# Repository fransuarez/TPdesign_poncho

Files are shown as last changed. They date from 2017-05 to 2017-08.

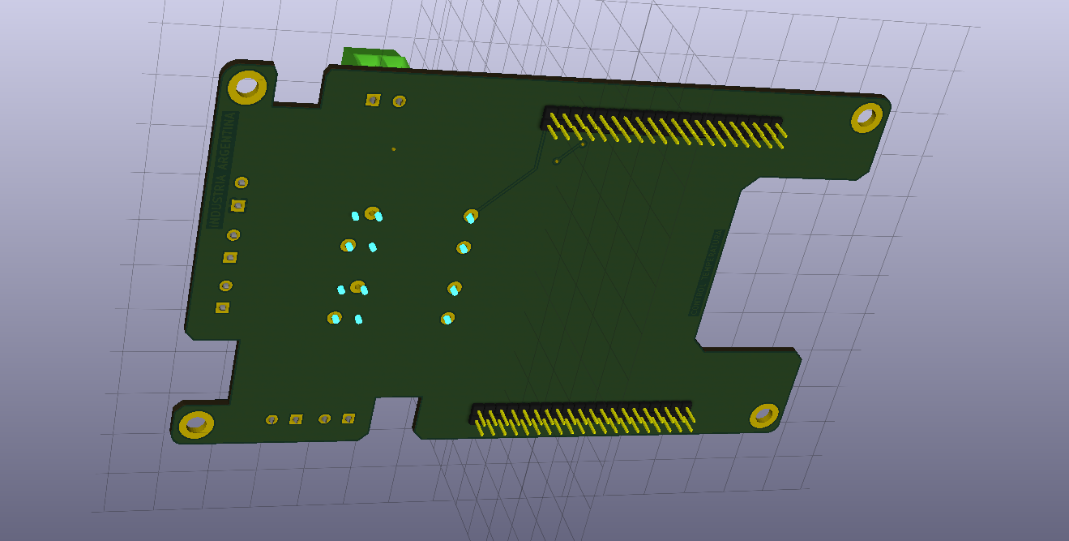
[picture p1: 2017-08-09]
Docs/tempRelayPoncho_BOTTOM.png

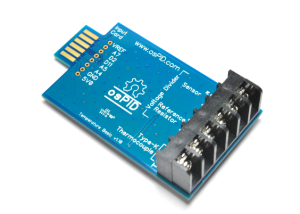
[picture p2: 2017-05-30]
Docs/osPID/osPIDInputTemperatureBasicBoard-300x214.png

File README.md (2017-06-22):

# TPdesign_poncho
Nombre corto del proyecto: 
Interfaz de termocupla K mas salidas a Relay

Autor:
Francisco Suárez

Fecha de este documento::

28 Mayo de 2017

Licencia:
BSD
GPL V3, Open Hardware

Descripción:
Es una poncho destinado a intermediar con termocuplas mas el control de dos interruptores a traves de relays, pensado para hacer control de temperatura en un tanque de agua a travez de resistencias.

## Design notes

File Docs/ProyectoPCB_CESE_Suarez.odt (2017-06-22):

Curso de Diseño de PCBs - CESE

Hoja de presentación de proyecto

Nombre corto del proyecto:

Interfaz de termocupla K mas salidas a Relay

Autor:

Francisco Suárez

Fecha de este documento::

28 Mayo de 2017

Licencia:

BSD

GPL V3, Open Hardware

Repositorio de trabajo:

https://github.com/fransuarez/TPdesign_poncho.git

Descripción:

Es una poncho destinado a intermediar con termocuplas mas el control de dos interruptores a traves de relays, pensado para hacer control de temperatura en un tanque de agua a travez de resistencias.

Requisitos del profesor:

Requisitos comunes:

1. Licencia abierta (se tiene que poder publicar los archivos KiCad y la funcionalidad del circuito).
2. Utilizar Kicad 4.0.x.
3. Consolidar toda la documentación en forma organizada dentro del directorio de proyecto de KiCad.
4. Aplicar una licencia o aclarar el Copyright.
5. Considerar en cada caso, los aspectos vistos referente a documentación.
6. Realizar diseño jerárquico salvo en circuitos muy pequeños.
7. Siempre que sea posible, considerar para los diseños componentes que se consigan en el mercado local.
8. Se utilizará como proveedor de referencia a Mayer (para las reglas de diseño).
9. Indicar que tipo/calidad de placa se considera para el diseño, intentando siempre que sea posible, seleccionar la de menor costo.

10. Pcb de dos capas.

Tareas y Alcance:

Indicar hasta donde se pretende llegar con el diseño y que tareas involucra. Por ejemplo:

1. Búsqueda de esquemáticos de referencia. (Obligatorio)
2. Adaptaciones de esquemático.
3. Ingreso de esquemático a Kicad. (Obligatorio)
4. Revisión del esquemático por un tercero. (Obligatorio)
5. Cálculo de presupuesto y proveedores de componentes. (Obligatorio)
6. Selección de footprints. (Obligatorio)
7. Ubicación de componentes. (Necesario para una buena calificación)
8. Ruteo. (Depende lo acordado)
9. Generación de Gerbers. (Depende lo acordado)

Enlaces:

http://ospid.com/blog/download/

https://github.com/osPID

Imágenes:

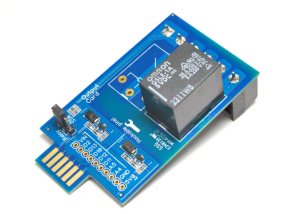
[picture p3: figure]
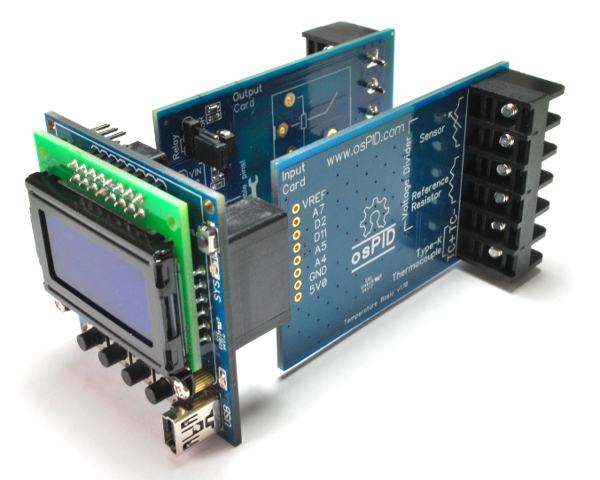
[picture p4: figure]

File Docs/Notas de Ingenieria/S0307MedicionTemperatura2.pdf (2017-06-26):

## TERMORRESISTENCIAS (RTD)

- La termorresistencia trabaja según el principio de que en la medida que varía la temperatura, su resistencia se modifica, y la magnitud de esta modificación puede relacionarse con la variación de temperatura.
- Las termorresistencias de uso más común se fabrican de alambres finos soportados por un material aislante y luego encapsulados.
- El elemento encapsulado se inserta luego dentro de una vaina o tubo metálico cerrado en un extremo que se llena con un polvo aislante y se sella con cemento para impedir que absorba humedad.

## TERMORRESISTENCIAS (RTD)

- La relación fundamental para el funcionamiento es:
- Rt = Ro * (1 + α * t)
- Ro: resistencia en ohmios a 0 grados Celsius
- Rt: resistencia en ohmios a t grados Celsius
- Alpha: coeficiente de temperatura de la resistencia. Los materiales utilizados para los arrollamientos de termorresistencias son fundamentalmente platino, níquel, níquel-hierro, cobre y tungsteno.

## TERMORRESISTENCIAS (RTD)

- El platino encuentra aplicación dentro de un amplio rango de temperaturas y es el material más estable y exacto.
- En efecto, la relación resistencia-temperatura correspondiente al alambre de platino es tan reproducible que la termorresistencia de platino se utiliza como estándar internacional de temperatura desde -260ºC hasta 630ºC .

## TERMORRESISTENCIAS (RTD)

RANGO DE OPERACIÓN | PRECISIÓN
| (ºC) | (grados)
Platino -200 a 950 | 0.01
Níquel | -150 a 300 | 0.50
Cobre | -200 a 120 | 0.10

## TERMORRESISTENCIAS (RTD)

- En general el sensor viene introducido dentro de un tubo protector metálico de acero inoxidable o construido de aceros especiales o aleaciones, como el Inconel, Incoloy y Hastelloy.
- Su construcción puede hacerse con 2, 3 o 4 cables, según la necesidad del proceso.
- La interconexión entre termorresistencias e instrumentos se realiza con cable común de cobre.
- En cambio, en el caso de las termocuplas deben emplearse cables especiales de compensación, de costo superior.

## TERMORRESISTENCIAS (RTD)

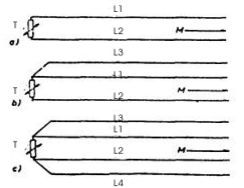
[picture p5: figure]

Construcción de termorresistencias

- El aspecto exterior de las termorresistencias industriales es prácticamente idéntico al de las termocuplas.
- Se aplican las mismas consideraciones ambientales y de instalación y se debe prestar la misma atención a los conceptos de presión, temperatura, ataque químico, abrasión, vibración, porosidad y velocidad de fluido, requiriéndose los mismos tipos de vainas de protección.

Construcción de termorresistencias

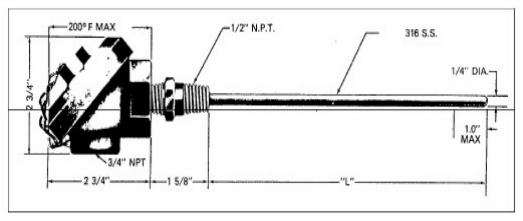
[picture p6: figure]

Construcción de termorresistencias

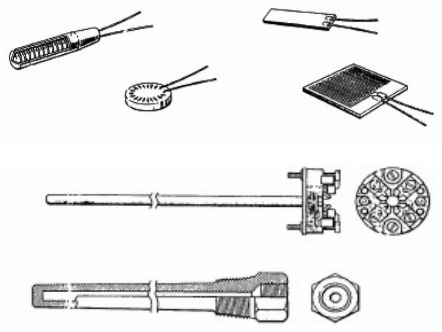
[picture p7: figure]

## TERMISTORES

- Compuesto de una mezcla sintetizada de óxidos metálicos, el termistor es esencialmente un semiconductor que se comporta como un "resistor térmico" con un coeficiente térmico de temperatura negativo de valor muy elevado.
- Los termistores también se pueden encontrar en el mercado con la denominación NTC (Negative Temperature Coeficient).
- RT = Ro exp [B (1/T - 1/To)]

- En algunos casos, la resistencia de un termistor a la temperatura ambiente puede disminuir hasta 6% por cada 1ºC de aumento de temperatura.
- Esta elevada sensibilidad a variaciones de temperatura hace que el termistor resulte muy adecuado para mediciones precisas de temperatura, utilizándoselo ampliamente para aplicaciones de control y compensación en el rango de 150ºC a 450ºC.

## TERMISTORES

- El termistor se fabrica a partir de óxidos metálicos comprimidos y sintetizados.
- Los metales utilizados son níquel, cobalto, manganeso, hierro, cobre, magnesio y titanio.
- Se pueden considerar típicas, las preparaciones de óxido de manganeso con cobre y óxido de níquel con cobre.
- Modificando las proporciones de óxido, se puede variar la resistencia básica un termistor.
- Se dispone de termistores con resistencias básicas a 25ºC desde unos pocos cientos hasta varios millones de ohms.

## TERMISTORES

- Los termistores sirven para la medición o detección de temperatura, tanto en gases como en líquidos o sólidos.
- A causa de su muy pequeño tamaño, se los encuentra normalmente montados en sondas o alojamientos especiales que pueden ser específicamente diseñados para posicionarlos y protegerlos adecuadamente cualquiera sea el medio donde tengan que trabajar.
- Los alojamientos pueden ser de acero inoxidable, aluminio, plástico, bronce u otros materiales.

## TERMISTORES

- Las configuraciones constructivas del termistor de uso más común son los glóbulos, las sondas y los discos.
- Los glóbulos se fabrican formando pequeñas elipsoides de material de termistor sobre dos alambres finos separados unos 0,25 mm. Normalmente recubiertos con vidrio por razones de protección, son extremadamente pequeños (0,15 mm a 1,3 mm de diámetro) y ofrecen una respuesta extremadamente rápida a variaciones de temperatura.

## TERMISTORES

a.- Tipo glóbulo, con diferentes tipos de terminales. b.- Tipo disco
c.- Tipo barra

Formas constructivas de termistores NTC

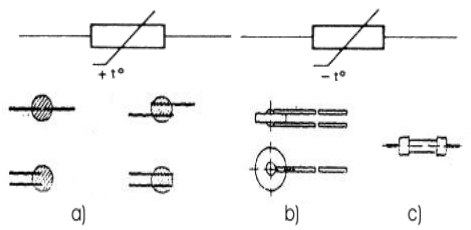
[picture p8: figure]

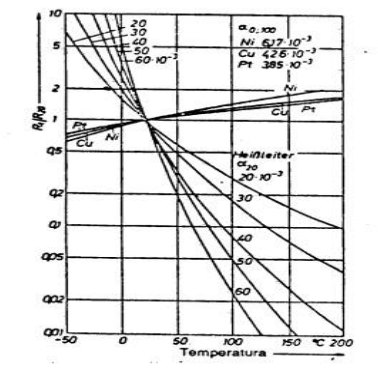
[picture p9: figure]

## PIRÓMETRO ÓPTICO Y DE RADIACIÓN

- Rangos de medición de temperaturas superiores al de cualquier otro instrumento.
- No requieren conexión física con el medio
- En el pirómetro óptico se compara el brillo de un filamento de una lámpara calibrada con el del objeto caliente.
- En el pirómetro de radiación se mide la energía neta irradiada por el objeto
- Poseen respuesta rápida y su exactitud es excelente.

## PIRÓMETRO ÓPTICO Y DE RADIACIÓN

- Pueden utilizarse para:
– Medir temperaturas que están por encima de las que pueden medir las termocuplas o termoresistencias. – Medir temperaturas donde la atmósfera o las condiciones impidan el uso de otro método.
– Medir temperaturas de objetos que se mueven.
– Medir temperaturas de objetos que no son accesibles. – Medir temperaturas de objetos que serías dañados si se les conecta un elemento primario.
– Medir temperaturas promedio de superficies muy grandes.

### Diagrama de un pirómetro de radiación visible

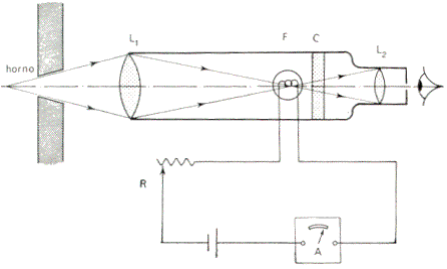
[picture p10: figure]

## PIRÓMETROS DE RADIACIÓN

- Todos los objetos a temperatura por encima del cero absoluto emiten radiación electromagnética en función de la temperatura.
- La cantidad de radiación electromagnética depende de la temperatura del cuerpo. A mayor temperatura, más intensa es la radiación

## PIRÓMETROS DE RADIACIÓN

OPERACIÓN
- El sistema óptico del termómetro de radiación recolecta parte de la radiación proveniente de una muestra de la superficie y la dirige al detector. El cual la convierte en una señal eléctrica.
- El circuito electrónico convierte la señal eléctrica a una correspondiente a la temperatura de la superficie.

## PIRÓMETROS DE RADIACIÓN

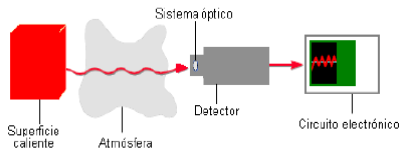
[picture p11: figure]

## PIRÓMETROS DE RADIACIÓN

### Transmisores de Temperatura

Sensor Type | Limits of Application (°C) | Advantages | Disadvantages
type E: chromel-constantan | -100 to 1000 | -good reproducibility -wide range | -minimum span of 40 °C
type J: iron-constantan | 0 to 750 | | -temperature vs. emf not exactly linear -drift over time -low emf corrupted by noise
type K: chromel-nickel | 0 to 1250
type T: copper-constantan | -160 to 400
RTD | -200 to 650 | -good accuracy -small span possible -linearity | -self-heating -less physically rugged -self-heating error -highly nonlinear
Thermister | -40 to 150 | -good accuracy -little drift | -only small span -less physically rugged -drift
Bimetallic | - | -low cost -physically rugged | -local display
Filled system | -200 to 800 | -simple and low cost -no hazards | -not high temperatures -sensitive to external pressure

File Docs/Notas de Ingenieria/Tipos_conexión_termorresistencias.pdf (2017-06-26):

# Termorresistencias -Tipos de conexión

La puesta en servicio de las termorresistencias se efectúa con un cable de cobre de 2, 3 o 4 hilos

Los montajes clásicos se resumen en:

1- Montaje 2 hilos.

No aconsejable si la distancia entre la termorresistencia y el aparato sobrepasa los 10 metros.
En este tipo de montajes la resistencia de las líneas esta en serie con la de la termorresistencia e interviene en la medida global. Si la resistencia entre el captador y el aparato de medida es grande, las variaciones de la temperatura ambiente pueden perturbar la medida.

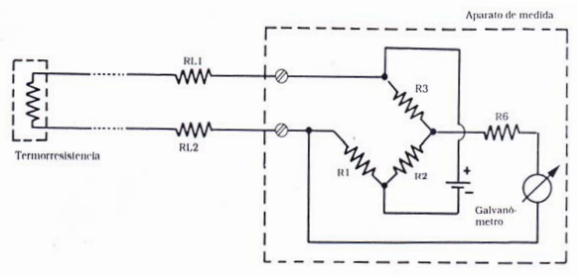
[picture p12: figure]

### 2- Montaje 3 hilos

Aconsejado en instalaciones industriales. Este tipo de montajes interviene la resistencia de cada línea, una en serie con el captador y otra en serie con la resistencia R3 que es simétrica en el puente. Cualquiera que sea la longitud de los conductores, la variación de la
resistencia | del | captador | es
prácticamente equivalente a la variación de la temperatura.

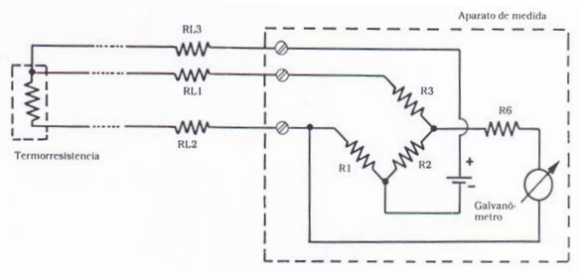
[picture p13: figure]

### 3- Montaje 4 hilos

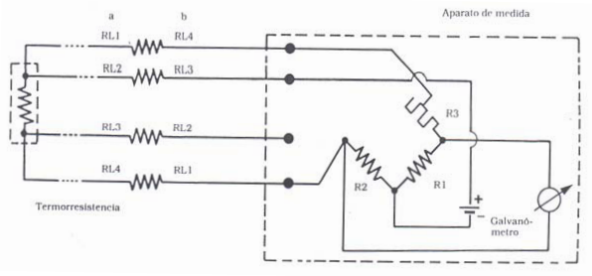
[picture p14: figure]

Aconsejado para medidas en laboratorio. Este montaje es utilizado para realizar mediciones de gran precisión, por potenciómetro o puente de wheatstone
equilibrado. | Con | este | tipo | de
conexionado la influencia de las resistencias en línea se encuentra totalmente anulada.

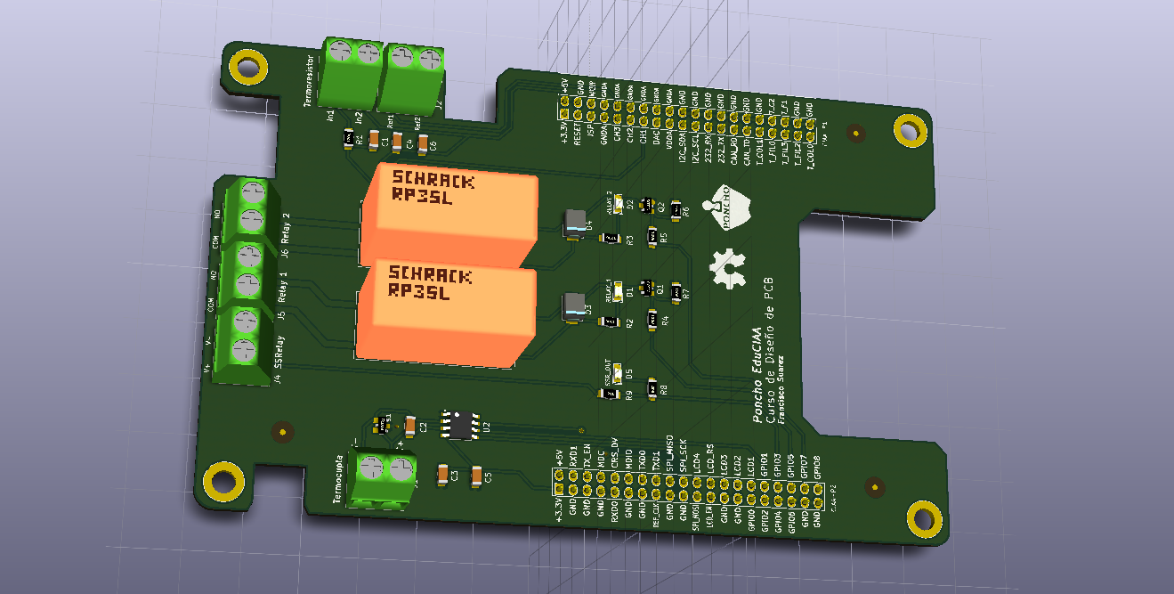
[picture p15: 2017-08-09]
Docs/tempRelayPoncho_TOP.png

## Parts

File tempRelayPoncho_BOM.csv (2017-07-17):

Source: | /home/fran/CIAA/Repositorios/TPpcbdesign/tempRelayPoncho.sch
Date: | Sun 16 Jul 2017 10:07:31 PM ART
Tool: | Eeschema 4.0.6-e0-6349~53~ubuntu16.04.1
Generator: | /home/fran/Documents/Diseño de circuitos impresos/TPs/practica2/tools/bom_csv_grouped_by_value.py
Component Count: | 37
Individual Components:
Item | Qty | Reference(s) | Value | LibPart | Footprint | Datasheet | Descripcion | Description | Digikey# | Manf | Manf# | Mouser#
 |  | C1 | 10u | TempRelay:C | footprints:C_0805_HandSoldering | c02e-2905.pdf |  | Multilayer Ceramic Capacitors MLCC - SMD/SMT 0805 10uF 6.3volts X5R 20% | 490-1718-1-ND | Murata | GRM21BR60J106ME19L | 81-GRM21BR60J106ME19
 |  | C2 | 100n | TempRelay:C | footprints:C_0805_HandSoldering | c02e-2905.pdf |  | Multilayer Ceramic Capacitors MLCC - SMD/SMT 0.1uF 10Volts U2J 5% | 490-11592-1-ND | Murata | GRM21B7U1A104JA01L | 81-GRM21B7U1A104JA1L
 |  | C3 | 10u | TempRelay:C | footprints:C_0805_HandSoldering | c02e-2905.pdf |  | Multilayer Ceramic Capacitors MLCC - SMD/SMT 0805 10uF 6.3volts X5R 20% | 490-1718-1-ND | Murata | GRM21BR60J106ME19L | 81-GRM21BR60J106ME19
 |  | C4 | 10u | TempRelay:C | footprints:C_0805_HandSoldering | c02e-2905.pdf |  | Multilayer Ceramic Capacitors MLCC - SMD/SMT 0805 10uF 6.3volts X5R 20% | 490-1718-1-ND | Murata | GRM21BR60J106ME19L | 81-GRM21BR60J106ME19
 |  | C5 | 100n | TempRelay:C | footprints:C_0805_HandSoldering | c02e-2905.pdf |  | Multilayer Ceramic Capacitors MLCC - SMD/SMT 0.1uF 10Volts U2J 5% | 490-11592-1-ND | Murata | GRM21B7U1A104JA01L | 81-GRM21B7U1A104JA1L
 |  | C6 | 100n | TempRelay:C | footprints:C_0805_HandSoldering | c02e-2905.pdf |  | Multilayer Ceramic Capacitors MLCC - SMD/SMT 0.1uF 10Volts U2J 5% | 490-11592-1-ND | Murata | GRM21B7U1A104JA01L | 81-GRM21B7U1A104JA1L
 |  | D1 | LED_ALT | TempRelay:LED_ALT | footprints:LED-0805 | qtlp630c-2.pdf |  | Red 645nm LED Indication - Discrete 1.9V 0805 (2012 Metric) | 1080-1412-2-ND | Everlight Electronics Co Ltd | QTLP630C7TR | Value
 |  | D2 | LED_ALT | TempRelay:LED_ALT | footprints:LED-0805 | qtlp630c-2.pdf |  | Red 645nm LED Indication - Discrete 1.9V 0805 (2012 Metric) | 1080-1412-2-ND | Everlight Electronics Co Ltd | QTLP630C7TR | Value
 |  | D3 | MRA4003T3G | TempRelay:DIODE | footprints:DO-214AA(SMB) | MRA4003T3-D.PDF |  | Diode Standard 300V 1A SMA | MRA4003T3GOSTR-ND | ON Semiconductor | MRA4003T3G | Value
 |  | D4 | MRA4003T3G | TempRelay:DIODE | footprints:DO-214AA(SMB) | MRA4003T3-D.PDF |  | Diode Standard 300V 1A SMA | MRA4003T3GOSTR-ND | ON Semiconductor | MRA4003T3G | Value
 |  | D5 | LED_ALT | TempRelay:LED_ALT | footprints:LED-0805 | qtlp630c-2.pdf |  | Red 645nm LED Indication - Discrete 1.9V 0805 (2012 Metric) | 1080-1412-2-ND | Everlight Electronics Co Ltd | QTLP630C7TR | Value
 |  | F1 | FIDUCIAL | TempRelay:FIDUCIAL | footprints:Fiducial_1mm |  | FIDUCIAL
 |  | F2 | FIDUCIAL | TempRelay:FIDUCIAL | footprints:Fiducial_1mm |  | FIDUCIAL
 |  | F3 | FIDUCIAL | TempRelay:FIDUCIAL | footprints:Fiducial_1mm |  | FIDUCIAL
 |  | J1 | Screw_Terminal_1x02 | TempRelay:Screw_Terminal_1x02 | footprints:TerminalBlock_Pheonix_MKDS1.5-2pol | MKDS Phoenix 1-5.pdf |  | 2 Position Wire to Board Terminal Block Horizontal with Board 0.138 | 277-5719-ND | Phoenix Contact | 1751248 | Value
 |  | J2 | Screw_Terminal_1x02 | TempRelay:Screw_Terminal_1x02 | footprints:TerminalBlock_Pheonix_MKDS1.5-2pol | MKDS Phoenix 1-5.pdf |  | 2 Position Wire to Board Terminal Block Horizontal with Board 0.138 | 277-5719-ND | Phoenix Contact | 1751248 | Value
 |  | J3 | Screw_Terminal_1x02 | TempRelay:Screw_Terminal_1x02 | footprints:TerminalBlock_Pheonix_MKDS1.5-2pol | MKDS Phoenix 1-5.pdf |  | 2 Position Wire to Board Terminal Block Horizontal with Board 0.138 | 277-5719-ND | Phoenix Contact | 1751248 | Value
 |  | J4 | Screw_Terminal_1x02 | TempRelay:Screw_Terminal_1x02 | footprints:TerminalBlock_Pheonix_MKDS1.5-2pol | MKDS Phoenix 1-5.pdf |  | 2 Position Wire to Board Terminal Block Horizontal with Board 0.138" (3.50mm) Through Hole | 277-5719-ND | Phoenix Contact | 1751248 | Value
 |  | J5 | Screw_Terminal_1x02 | TempRelay:Screw_Terminal_1x02 | footprints:TerminalBlock_Pheonix_MKDS1.5-2pol | MKDS Phoenix 1-5.pdf |  | 2 Position Wire to Board Terminal Block Horizontal with Board 0.138" (3.50mm) Through Hole | 277-5719-ND | Phoenix Contact | 1751248 | Value
 |  | J6 | Screw_Terminal_1x02 | TempRelay:Screw_Terminal_1x02 | footprints:TerminalBlock_Pheonix_MKDS1.5-2pol | MKDS Phoenix 1-5.pdf |  | 2 Position Wire to Board Terminal Block Horizontal with Board 0.138" (3.50mm) Through Hole | 277-5719-ND | Phoenix Contact | 1751248 | Value
 |  | Q1 | MMBT3904 | TempRelay:MMBT3904 | footprints:SOT23_NPN | 2N3904-82270.pdf |  | Bipolar (BJT) Transistor NPN 40V 200mA 300MHz 350mW | MMBT3904FSCT-ND | ON Semiconductor | MMBT3904 | Value
 |  | Q2 | MMBT3904 | TempRelay:MMBT3904 | footprints:SOT23_NPN | 2N3904-82270.pdf |  | Bipolar (BJT) Transistor NPN 40V 200mA 300MHz 350mW | MMBT3904FSCT-ND | ON Semiconductor | MMBT3904 | Value
 |  | R1 | 10k | TempRelay:R | footprints:R_0805_HandSoldering | Yageo_08112016_RC0805-968729.pdf |  | Thick Film Resistors - SMD 10K OHM 1% | 311-10.0KCRCT-ND | Yageo | RC0805FR-0710KL | 603-RC0805FR-0710KL
 |  | R2 | 1k | TempRelay:R | footprints:R_0805_HandSoldering | ../Datasheets/Yageo_08112016_RC0805-968729.pdf |  | Thick Film Resistors - SMD 1K OHM 1% | 311-1.00KCRCT-ND | Yageo | RC0805FR-071KL | 603-RC0805FR-071KL
 |  | R3 | 1k | TempRelay:R | footprints:R_0805_HandSoldering | ../Datasheets/Yageo_08112016_RC0805-968729.pdf |  | Thick Film Resistors - SMD 1K OHM 1% | 311-1.00KCRCT-ND | Yageo | RC0805FR-071KL | 603-RC0805FR-071KL
 |  | R4 | 1k | TempRelay:R | footprints:R_0805_HandSoldering | ../Datasheets/Yageo_08112016_RC0805-968729.pdf |  | Thick Film Resistors - SMD 1K OHM 1% | 311-1.00KCRCT-ND | Yageo | RC0805FR-071KL | 603-RC0805FR-071KL
 |  | R5 | 1k | TempRelay:R | footprints:R_0805_HandSoldering | ../Datasheets/Yageo_08112016_RC0805-968729.pdf |  | Thick Film Resistors - SMD 1K OHM 1% | 311-1.00KCRCT-ND | Yageo | RC0805FR-071KL | 603-RC0805FR-071KL
 |  | R6 | 10k | TempRelay:R | footprints:R_0805_HandSoldering | ../Datasheets/Yageo_08112016_RC0805-968729.pdf |  | Thick Film Resistors - SMD 10K OHM 1% | 311-10.0KCRCT-ND | Yageo | RC0805FR-0710KL | 603-RC0805FR-0710KL
 |  | R7 | 10k | TempRelay:R | footprints:R_0805_HandSoldering | ../Datasheets/Yageo_08112016_RC0805-968729.pdf |  | Thick Film Resistors - SMD 10K OHM 1% | 311-10.0KCRCT-ND | Yageo | RC0805FR-0710KL | 603-RC0805FR-0710KL
 |  | R8 | 1k | TempRelay:R | footprints:R_0805_HandSoldering | ../Datasheets/Yageo_08112016_RC0805-968729.pdf |  | Thick Film Resistors - SMD 1K OHM 1% | 311-1.00KCRCT-ND | Yageo | RC0805FR-071KL | 603-RC0805FR-071KL
 |  | R9 | 100 | TempRelay:R | footprints:R_0805_HandSoldering | ../Datasheets/Yageo_08112016_RC0805-968729.pdf |  | 1Thick Film Resistors - SMD 100 OHM 1% | 311-100CRCT-ND | Yageo | RC0805FR-07100RL | 603-RC0805FR-07100RL
 |  | U1 | NUP2105LT1G | TempRelay:NUP2105LT1G | footprints:SC-59_Handsoldering | NUP2105L-D-771105.pdf |  | TVS DIODE 24VWM 44VC | NUP2105LT1GOSCT-ND | ON Semiconductor | NUP2105LT1G | Value
 |  | U2 | MAX31855KASA+ | TempRelay:MAX31855KASA+ | footprints:SOIC-8 | MAX31855.pdf |  | Sensor Interface Thermocouple To Digital Converter | MAX31855KASA+-ND | Maxim Integrated | MAX31855KASA+ | Value
 |  | U3 | MCP601R | TempRelay:MCP601R | footprints:SOT-23-5_HandSoldering | MCP601,2,3,4.pdf |  | Operational Amplifiers - Op Amps Single 2.7V | Value | Microchip Technology | MCP601T-I/OT | 579-MCP601T-I/OT
 |  | U4 | G5LE-1A-5DC | TempRelay:G5LE-1A-5DC | footprints:Relay_G5LE-1A-5DC-5mm
 |  | U6 | G5LE-1A-5DC | TempRelay:G5LE-1A-5DC | footprints:Relay_G5LE-1A-5DC-5mm
 |  | XA1 | Conn_Poncho2P_2x_20x2 | TempRelay:Conn_Poncho2P_2x_20x2 | footprints:Conn_Poncho_Completo |  |  | Value | Value | Value | Value | Value
Collated Components:
Item | Qty | Reference(s) | Value | LibPart | Footprint | Datasheet | Descripcion | Description | Digikey# | Manf | Manf# | Mouser#
1 | 3 | C1, C3, C4 | 10u | TempRelay:C | footprints:C_0805_HandSoldering | c02e-2905.pdf |  | Multilayer Ceramic Capacitors MLCC - SMD/SMT 0805 10uF 6.3volts X5R 20% | 490-1718-1-ND | Murata | GRM21BR60J106ME19L | 81-GRM21BR60J106ME19
2 | 3 | C2, C5, C6 | 100n | TempRelay:C | footprints:C_0805_HandSoldering | c02e-2905.pdf |  | Multilayer Ceramic Capacitors MLCC - SMD/SMT 0.1uF 10Volts U2J 5% | 490-11592-1-ND | Murata | GRM21B7U1A104JA01L | 81-GRM21B7U1A104JA1L
3 | 3 | D1, D2, D5 | LED_ALT | TempRelay:LED_ALT | footprints:LED-0805 | qtlp630c-2.pdf |  | Red 645nm LED Indication - Discrete 1.9V 0805 (2012 Metric) | 1080-1412-2-ND | Everlight Electronics Co Ltd | QTLP630C7TR | Value
4 | 2 | D3, D4 | MRA4003T3G | TempRelay:DIODE | footprints:DO-214AA(SMB) | MRA4003T3-D.PDF |  | Diode Standard 300V 1A SMA | MRA4003T3GOSTR-ND | ON Semiconductor | MRA4003T3G | Value
5 | 3 | F1, F2, F3 | FIDUCIAL | TempRelay:FIDUCIAL | footprints:Fiducial_1mm |  | FIDUCIAL
6 | 6 | J1, J2, J3, J4, J5, J6 | Screw_Terminal_1x02 | TempRelay:Screw_Terminal_1x02 | footprints:TerminalBlock_Pheonix_MKDS1.5-2pol | MKDS Phoenix 1-5.pdf |  | 2 Position Wire to Board Terminal Block Horizontal with Board 0.138 | 277-5719-ND | Phoenix Contact | 1751248 | Value
7 | 2 | Q1, Q2 | MMBT3904 | TempRelay:MMBT3904 | footprints:SOT23_NPN | 2N3904-82270.pdf |  | Bipolar (BJT) Transistor NPN 40V 200mA 300MHz 350mW | MMBT3904FSCT-ND | ON Semiconductor | MMBT3904 | Value
8 | 3 | R1, R6, R7 | 10k | TempRelay:R | footprints:R_0805_HandSoldering | Yageo_08112016_RC0805-968729.pdf |  | Thick Film Resistors - SMD 10K OHM 1% | 311-10.0KCRCT-ND | Yageo | RC0805FR-0710KL | 603-RC0805FR-0710KL
9 | 5 | R2, R3, R4, R5, R8 | 1k | TempRelay:R | footprints:R_0805_HandSoldering | ../Datasheets/Yageo_08112016_RC0805-968729.pdf |  | Thick Film Resistors - SMD 1K OHM 1% | 311-1.00KCRCT-ND | Yageo | RC0805FR-071KL | 603-RC0805FR-071KL
10 | 1 | R9 | 100 | TempRelay:R | footprints:R_0805_HandSoldering | ../Datasheets/Yageo_08112016_RC0805-968729.pdf |  | 1Thick Film Resistors - SMD 100 OHM 1% | 311-100CRCT-ND | Yageo | RC0805FR-07100RL | 603-RC0805FR-07100RL
11 | 1 | U1 | NUP2105LT1G | TempRelay:NUP2105LT1G | footprints:SC-59_Handsoldering | NUP2105L-D-771105.pdf |  | TVS DIODE 24VWM 44VC | NUP2105LT1GOSCT-ND | ON Semiconductor | NUP2105LT1G | Value
12 | 1 | U2 | MAX31855KASA+ | TempRelay:MAX31855KASA+ | footprints:SOIC-8 | MAX31855.pdf |  | Sensor Interface Thermocouple To Digital Converter | MAX31855KASA+-ND | Maxim Integrated | MAX31855KASA+ | Value
13 | 1 | U3 | MCP601R | TempRelay:MCP601R | footprints:SOT-23-5_HandSoldering | MCP601,2,3,4.pdf |  | Operational Amplifiers - Op Amps Single 2.7V | Value | Microchip Technology | MCP601T-I/OT | 579-MCP601T-I/OT
14 | 2 | U4, U6 | G5LE-1A-5DC | TempRelay:G5LE-1A-5DC | footprints:Relay_G5LE-1A-5DC-5mm
15 | 1 | XA1 | Conn_Poncho2P_2x_20x2 | TempRelay:Conn_Poncho2P_2x_20x2 | footprints:Conn_Poncho_Completo |  |  | Value | Value | Value | Value | Value

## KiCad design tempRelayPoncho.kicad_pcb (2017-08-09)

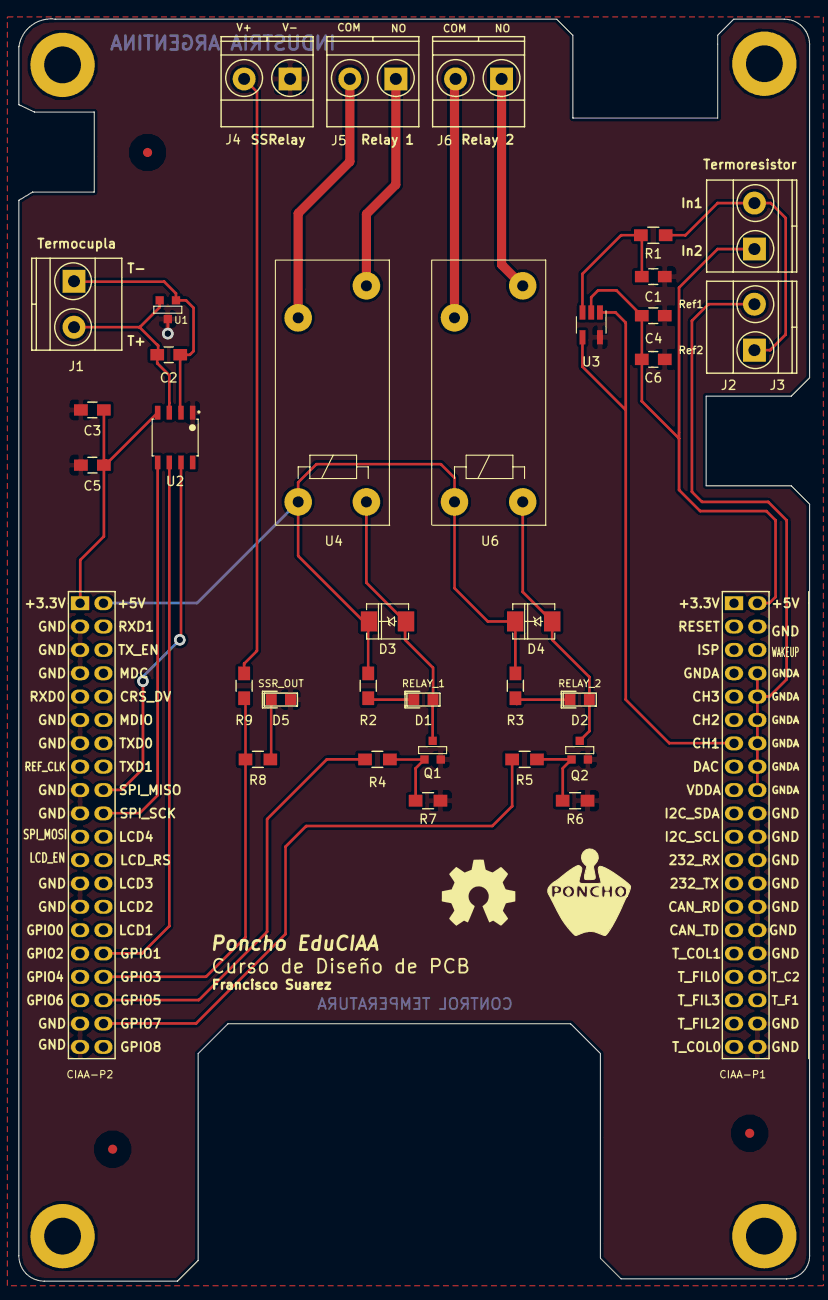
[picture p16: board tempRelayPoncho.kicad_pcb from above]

Board: 2 copper layers, 86.0 x 137.3 mm, 38 parts (0 on the bottom side), 28 nets.

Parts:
C1, C3, C4: 10u; C_0805_HandSoldering
C2, C5, C6: 100n; C_0805_HandSoldering
D1: RELAY_1; LED-0805
D2: RELAY_2; LED-0805
D3, D4: MRA4003T3G; DO-214AA(SMB)
D5: SSR_OUT; LED-0805
F1, F2, F3: FIDUCIAL; Fiducial_1mm
G101: Logo_OSHWA
J1, J2, J3, J4, J5, J6: Screw_Terminal_1x02; TerminalBlock_Pheonix_MKDS1.5-2pol
Q1, Q2: MMBT3904; SOT23_NPN
R1, R6, R7: 10k; R_0805_HandSoldering
R2, R3, R4, R5, R8: 1k; R_0805_HandSoldering
R9: 100; R_0805_HandSoldering
U1: NUP2105LT1G; SOT23_NPN
U2: MAX31855KASA+; SOIC-8
U3: MCP601R; SOT-23-5_HandSoldering
U4, U6: G5LE-1A-5DC; Relay_G5LE-1A-5DC-5mm
XA1: Conn_Poncho2P_2x_20x2; Conn_Poncho_Completo

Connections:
+3V3: C3.2, C5.2, U2.4, XA1.41
+5V: C4.2, C6.2, J2.1, U3.2, XA1.2
+5VD: D3.2, D4.2, R2.2, R3.2, U4.5, U6.5, XA1.42
/conector_ciaa/ADC_1: U3.1, U3.4, XA1.13
/conector_ciaa/GPIO_1: U2.6, XA1.72
/conector_ciaa/GPIO_3: R8.2, R9.2, XA1.74
/conector_ciaa/GPIO_5: R4.2, XA1.76
/conector_ciaa/GPIO_7: R5.2, XA1.78
/inputs_temp/MISO_TCUP: U2.7, XA1.58
/inputs_temp/SCK_TCUP: U2.5, XA1.60
GND: C1.1, C3.1, C4.1, C5.1, C6.1, D5.1, J4.1, Q1.2, Q2.2, R6.1, R7.1, U1.3, U2.1, U3.5, XA1.4, XA1.20, XA1.22, XA1.24, XA1.26, XA1.28, XA1.30, XA1.32, XA1.38, XA1.40, XA1.43, XA1.45, XA1.47, XA1.51, XA1.53, XA1.57, XA1.59, XA1.65, XA1.67, XA1.77, XA1.79
GNDA: J3.2, XA1.8, XA1.10, XA1.12, XA1.14, XA1.16, XA1.18
unnamed: C1.2, R1.1, U3.3
unnamed: C2.1, J1.2, U1.2, U2.3
unnamed: C2.2, J1.1, U1.1, U2.2
unnamed: D1.1, D3.1, Q1.3, U4.1
unnamed: D1.2, R2.1
unnamed: D2.1, D4.1, Q2.3, U6.1
unnamed: D2.2, R3.1
unnamed: D5.2, R8.1
unnamed: J2.2, J3.1, R1.2
unnamed: J4.2, R9.1
unnamed: J5.1, U4.3
unnamed: J5.2, U4.4
unnamed: J6.1, U6.3
unnamed: J6.2, U6.4
unnamed: Q1.1, R4.1, R7.2
unnamed: Q2.1, R5.1, R6.2

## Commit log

2017-05-30 Inicio de repositorio
    [tempRalayPoncho.kicad_pcb, tempRalayPoncho.sch]
2017-06-22 Primeros pasos
    Agrego primeros esquematicos y datasheets.
    [conector_ciaa.sch, inputs_temp.sch, output_digital.sch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]
2017-06-25 Primer version
    Esquematico completo, faltan notas del revisor.
    [conector_ciaa.sch, inputs_temp.sch, output_digital.sch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]
2017-06-26 Primer revision
    Se agregar correcciones del revisor. Se modifica entrada termocupla.
    [conector_ciaa.sch, inputs_temp.sch, output_digital.sch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]
2017-07-04 Correciones y ubicacion en pcb
    Se corrige problema con archivo inputs_temp.sch
    Se corrige problema con footprints de Realys y transistores U4 y U6
    Se hace primera ubicacion tentativa en PCB de componentes.
    [conector_ciaa.sch, inputs_temp.sch, output_digital.sch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]
2017-07-16 Primer version del PCB
    Se agregan modificaciones segun primer correccion. Se carga primer version del PCB.
    [conector_ciaa.sch, inputs_temp.sch, output_digital.sch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]
2017-07-17 Correcciones de Revisor
    Se agregan algunas de las correcciones del revisor. Las que restan se implementaran luego.
    [tempRelayPoncho.kicad_pcb, tempRelayPoncho_BOM.csv]
2017-08-09 Correccion Final
    Se trabajo sobre correcciones de 2da revision. Se agregaron archivos gerbers, BOM, y objetos 3D
    [conector_ciaa.sch, inputs_temp.sch, output_digital.sch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]
2017-08-09 Pines al 3D
    Se agregan tiras de pines y capturas del modelo en la carpeta docs
    [tempRelayPoncho.kicad_pcb]
